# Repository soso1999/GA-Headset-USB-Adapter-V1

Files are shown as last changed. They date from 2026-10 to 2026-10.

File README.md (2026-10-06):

# GA Headset USB Adapter — Dual-GA Aviation Headset to USB for Flight Simulators

DIY-Adapter zum Anschluss eines Dual-GA-Headsets mit zwei Klinkensteckern, beispielsweise eines **Lightspeed Zulu 4**, an einen PC oder Flugsimulator über eine USB-Soundkarte.

> **Nur für PC-/Simulator-Nutzung. Kein zertifiziertes Luftfahrtgerät. Nicht im Flugzeug verwenden und nicht an Flugzeug-Audio-, Funk-, Intercom- oder Bordstromsysteme anschließen.**  
> Siehe [DISCLAIMER](DISCLAIMER.md).

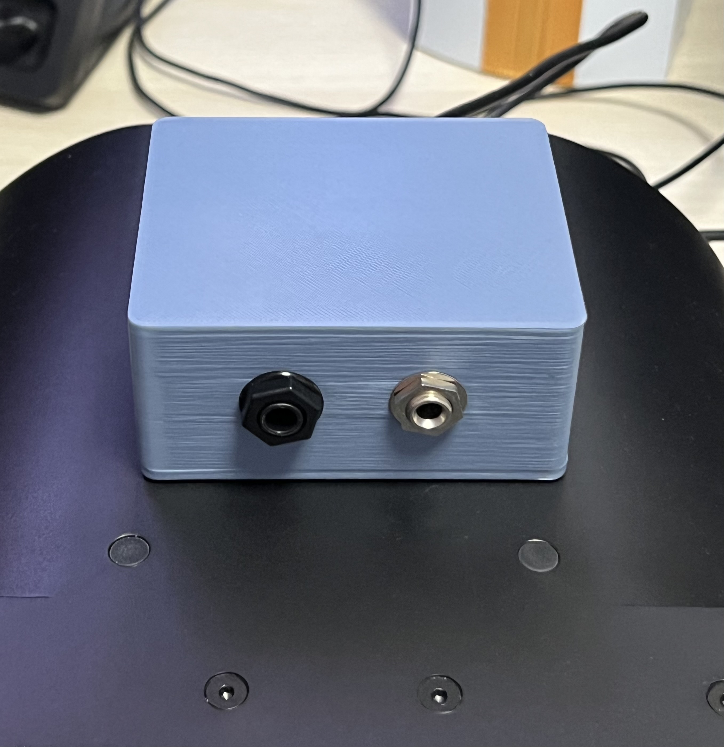
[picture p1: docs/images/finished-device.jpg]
GA Headset USB Adapter V1 für Lightspeed Zulu 4 und Flugsimulator


<a href="https://buymeacoffee.com/soso1999">
  Buy Me a Coffee
</a>

## Stand dieser Veröffentlichung

Der V1-Prototyp wurde gedruckt, aufgebaut und erfolgreich am PC getestet. Mikrofonaufnahme und Wiedergabequalität sind sehr gut.

Der Aufbau wurde erfolgreich mit einem **Lightspeed Zulu 4 Dual-GA** sowie einem **Bose QC35 II mit AVEE-Mikrofonadapter** getestet.

Dies ist die Dokumentation eines funktionierenden Einzelprototyps und keine messtechnische, sicherheitstechnische oder allgemeine Kompatibilitätsfreigabe.

**Dokumentationsstand: v1.0.0**

## Stückliste (BOM)

| Anzahl | Bauteil | Wert / Typ | Hinweise |
|---:|---|---|---|
| 1 | USB-Soundkarte | DollaTek Free Drive USB-Soundkarte | Stellt Mikrofoneingang und Stereo-Kopfhörerausgang bereit |
| 1 | DC-DC-Step-Up-Wandler | GTIWUNG 5 V → 12 V Boost Converter | Wird aus USB 5 V versorgt und erzeugt die Mikrofon-Bias-Spannung |
| 1 | Mikrofonbuchse | PJ-068 Aviation-Mikrofonbuchse | Für den GA-Mikrofonstecker |
| 1 | Kopfhörerbuchse | Neutrik NMJ3HF-S | 6,35 mm / 1/4" Stereo-Klinkenbuchse |
| 1 | Lochrasterplatine | ca. 60 × 40 mm | Abmessungen können je nach Aufbau variieren |
| 1 | Widerstand R1 | 22 Ω | Bestandteil des Versorgungsfilters |
| 1 | Widerstand R2 | 220 Ω | Bias-Widerstand für das Mikrofon |
| 1 | Widerstand R3 | 10 kΩ | Serienwiderstand zum Mikrofoneingang der USB-Soundkarte |
| 1 | Elko C1 | 470 µF / mindestens 25 V | Glättung der Versorgungsspannung; Polarität beachten |
| 1 | Keramikkondensator C2 | 100 nF / mindestens 25 V | HF-Entstörung der Versorgung |
| 1 | Folienkondensator C3 | 1 µF WIMA | Gleichspannungsentkopplung / Audio-Koppelkondensator |
| – | Schaltdraht / Litze | nach Aufbau | Interne Verdrahtung |
| – | Schrumpfschlauch / Isolierung | nach Aufbau | Zur elektrischen Isolation |
| 1 | USB-Anschlusskabel | USB-A-Stecker auf offenes Kabelende | Mindestens 4-adriges USB-2.0-Kabel für +5 V, GND, D+ und D− |
| 1 | 3D-gedrucktes Gehäuse | Eigenkonstruktion | Für 60 × 40 mm Platine und beide Aviation-Buchsen |
| 4 | M3-Schrauben | – | Für den Gehäusedeckel |
| 4 | M3-Gewindeeinsätze | Heat-Set Inserts | Werden mit dem Lötkolben in das Gehäuse eingeschmolzen |

Die ausführliche Stückliste befindet sich unter [hardware/BOM.md](hardware/BOM.md) bzw. [hardware/BOM.csv](hardware/BOM.csv).

Die 12-V-Mikrofon-Bias-Spannung des USB-Adapters versorgt ausschließlich das Elektret-Mikrofon. Sie speist nicht die ANR- oder Bluetooth-Elektronik des Headsets. Beim Lightspeed Zulu 4 Dual-GA erfolgt deren Versorgung weiterhin über die beiden AA-Batterien.

LEMO- und Helikopter-Stecker werden von dieser Version nicht unterstützt.

### Mikrofon-Signalweg

USB 5 V → Step-Up auf 12 V → 22-Ω-Filterwiderstand →  
gefilterter Versorgungspunkt mit 470-µF-Elko und 100-nF-Kondensator gegen GND →  
220-Ω-Mikrofon-Bias-Widerstand →  
Ring der PJ-068-Mikrofonbuchse

Mikrofon-Ring → 1-µF-Koppelkondensator → 10-kΩ-Widerstand →  
MIC-Eingang der USB-Soundkarte

PJ-068 Sleeve → gemeinsame Masse (GND)

PJ-068 Tip → nicht belegt

### Kopfhörerausgang

Der Stereo-Ausgang der USB-Soundkarte wird direkt an die 6,35-mm-Aviation-Kopfhörerbuchse geführt.

- Tip = linker Kanal
- Ring = rechter Kanal
- Sleeve = Masse (GND)

Eine zusätzliche Hardware-Mono-Mischung wird in Version 1 nicht verwendet.

Für eine korrekte Links-/Rechts-Kanaltrennung sollte das Headset auf Stereo gestellt werden. Beim Lightspeed Zulu 4 kann die Wiedergabe auch in der Stellung Mono normal funktionieren; dabei kann jedoch die echte Stereo-Kanaltrennung verloren gehen.

Alle Masseverbindungen der Schaltung verwenden einen gemeinsamen GND.

## Dokumentation und Dateien

| Inhalt | Datei |
|---|---|
| Stückliste | [BOM](hardware/BOM.md), [CSV](hardware/BOM.csv) |
| Elektrischer Schaltplan | [Schaltplan](hardware/schematic.md) |
| Anschluss für Anschluss | [Verdrahtung](docs/wiring.md) |
| Aufbau und Inbetriebnahme | [Bauanleitung](docs/build.md) |
| Störungen und bekannte Grenzen | [Troubleshooting](docs/troubleshooting.md) |
| Gehäuse und 3D-Druck | [CAD](cad/README.md) |
| Quellen und Projektstand | [Provenienz](docs/provenance.md) |
| Release Notes | [v1.0.0](releases/v1.0.0.md) |

## Prinzip

```text
                              ┌──────── Kopfhörer L ───── J2 Tip
PC ─ USB ─ USB-Soundkarte ────┼──────── Kopfhörer R ───── J2 Ring
       │                      └──────── Kopfhörer GND ─── J2 Sleeve
       │
       │                     MIC-IN
       │                        ↑
       │                      10 kΩ
       │                        ↑
       │                       C3
       │                        ↑
       │                 GA-Mikrofon-Ring
       │                        ↑
       │                      220 Ω
       │                        ↑
       └─ +5 V ─ Step-Up 12 V ─ Filter

Alle vorgesehenen Masseanschlüsse teilen einen gemeinsamen GND.
```

Der Kopfhörerausgang bleibt **Stereo**. Es findet keine passive Mono-Zusammenführung statt.

## Direct Monitoring / Sidetone

V1 enthält kein analoges Direct Monitoring bzw. Sidetone.

Software-Monitoring über Windows oder entsprechende Audio-Software ist möglich, kann jedoch eine deutlich hörbare Verzögerung verursachen.

Eine analoge Sidetone-/Preamp-Lösung ist als mögliche spätere V2 vorgesehen und nicht Bestandteil von V1.

## Unterstützung

Wenn dir das Projekt beim Einsatz deines Aviation-Headsets im Simulator hilft, kannst du die weitere Entwicklung freiwillig mit einem Kaffee unterstützen. Die Dateien bleiben frei verfügbar.

<a href="https://buymeacoffee.com/soso1999">
  Buy Me a Coffee
</a>

## Lizenz

Für die verschiedenen Bestandteile des Projekts gelten unterschiedliche Lizenzen:

- Hardware-Design, elektrische Schaltungs-/Verdrahtungsdokumentation und CAD-Dateien: **CERN Open Hardware Licence Version 2 – Permissive (`CERN-OHL-P-2.0`)**
- Allgemeine Dokumentation, README, Release Notes und Gerätefotos: **Creative Commons Attribution 4.0 International (`CC-BY-4.0`)**

Die vollständigen Lizenztexte und die genaue Zuordnung befinden sich unter [LICENSES](LICENSES/README.md).

Copyright © 2026 Josef Jankarashvili.

Lightspeed, Zulu, Bose und weitere genannte Hersteller- oder Produktnamen sind Marken ihrer jeweiligen Rechteinhaber. Dieses Projekt ist unabhängig und wird von den genannten Herstellern weder unterstützt noch zertifiziert.

Die elektrischen Herstellerdaten des Lightspeed Zulu 4 wurden anhand der [offiziellen Zulu-4-Spezifikation](https://www.lightspeedaviation.com/product/zulu-4-anr-headset/) geprüft. Weitere Quellen befinden sich in der Provenienz-Dokumentation.

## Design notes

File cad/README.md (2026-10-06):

# Gehäuse

| Teil | Datei |
|---|---|
| Unterteil | [ga_headset_interface_base.stl](stl/ga_headset_interface_base.stl) |
| Deckel | [ga_headset_interface_lid.stl](stl/ga_headset_interface_lid.stl) |
| Parametrische OpenSCAD-Quelldatei | [ga_headset_interface_case.scad](ga_headset_interface_case.scad) |

## Abmessungen

- Außenmaß des Gehäuses: 92 × 76 × 40 mm
- Wandstärke: 2,6 mm
- vorgesehene Platine: 60 × 40 mm
- Bohrung für GA-Mikrofonbuchse: ca. 9,7 mm
- Bohrung für 6,35-mm-Kopfhörerbuchse: ca. 11,5 mm
- USB-Kabelschlitz: 8 mm
- Aufnahmen für M3-Heat-Set-Inserts: ca. 4,2 mm
- vorgesehene Insert-Länge: ca. 5 mm

Die veröffentlichten STL-Dateien wurden für den V1-Prototyp gedruckt und erfolgreich mit der 60 × 40-mm-Platine sowie den verwendeten Buchsen montiert.

## Druckempfehlung

Als Material eignen sich PLA oder PETG.

Empfohlene Ausgangswerte:

- Schichthöhe: 0,2 mm
- mindestens drei Außenwände
- STL-Einheiten: Millimeter

Das Unterteil sollte mit dem Gehäuseboden auf dem Druckbett liegen. Der Deckel wird mit seiner flachen Außenseite auf dem Druckbett gedruckt.

Überhänge an den Buchsenöffnungen und inneren Auflagen sollten im Slicer kontrolliert werden. Falls erforderlich, können dort Stützstrukturen aktiviert werden.

Aufgrund von Drucker-, Material- und Slicer-Toleranzen empfiehlt es sich, insbesondere die Passung der Buchsen und Heat-Set-Inserts vor der endgültigen Montage zu kontrollieren.

## Montage

Die M3-Heat-Set-Inserts vorsichtig mit einem Lötkolben einschmelzen und rechtwinklig ausrichten.

Die Schraubenlänge entsprechend Deckeldicke, Insert-Tiefe und tatsächlich verfügbarem Gewinde wählen.

Die Platine elektrisch isoliert im Gehäuse befestigen. Das USB-Kabel sollte zusätzlich mechanisch zugentlastet werden.

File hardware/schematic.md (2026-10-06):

# Elektrischer Schaltplan — V1

Dieser Schaltplan dokumentiert den tatsächlich aufgebauten und getesteten Signalweg des GA-Headset-USB-Adapters V1. Die angegebenen Bauteilwerte entsprechen der funktionierenden V1-Hardware. Der Schaltplan stellt die elektrische Funktion dar und nicht zwingend die physische Anordnung der Bauteile auf der Lochrasterplatine.

```text
USB-A
├── +5 V ────────────────┬──────── U1 USB +5 V
│                        └──────── U2 IN+
│
├── D− ─────────────────────────── U1 USB D−
├── D+ ─────────────────────────── U1 USB D+
│
└── GND ────────────────┬──────── U1 USB GND
                        └──────── U2 IN−

U2 OUT− ────────────────────────── gemeinsame Masse
          (bei nicht isoliertem Step-Up mit IN− verbunden)

MIKROFONVERSORGUNG UND -SIGNAL

U2 OUT+ (12 V) ─ R1 22 Ω ─── ─┬── R2 220 Ω ────● MIC_BIAS_AUDIO
                              │                  │
                         ┌────┴────┐             ├── J1 Ring
                         │         │             │
                     C1 470 µF  C2 100 nF        └── C3 1 µF ─ R3 10 kΩ ─ U1 MIC signal
                     (+ oben)      │
                         │         │
GND ─────────────────────┴─────────┴──────────── J1 Sleeve / U1 MIC ground

J1 Tip: unbeschaltet
        (kein elektrisches PTT in diesem Adapter)

KOPFHÖRERAUSGANG

U1 Headphone L ─────────────────── J2 Tip
U1 Headphone R ─────────────────── J2 Ring
U1 Headphone GND ───────────────── J2 Sleeve ─ GND

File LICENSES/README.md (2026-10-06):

# Lizenzzuordnung

Copyright © 2026 Josef Jankarashvili.

Für die verschiedenen Bestandteile dieses Projekts gelten folgende Lizenzen:

- `cad/**`, `hardware/**` sowie die elektrische Schaltungs-, Verdrahtungs- und Aufbaudokumentation:
  **CERN Open Hardware Licence Version 2 – Permissive (`CERN-OHL-P-2.0`)**.  
  Der vollständige Lizenztext befindet sich unter `LICENSES/CERN-OHL-P-2.0.txt`.

- Allgemeine Dokumentation, `README.md`, Release Notes, Fotos und sonstige nicht zur Hardwarekonstruktion gehörende Inhalte:
  **Creative Commons Attribution 4.0 International (`CC-BY-4.0`)**.  
  Der vollständige Lizenztext befindet sich unter `LICENSES/CC-BY-4.0.txt`.

Die Lizenztexte selbst bleiben unverändert und werden unter den Bedingungen ihrer jeweiligen Urheber bereitgestellt.

Bei Weitergabe oder Bearbeitung müssen die jeweils geltenden Lizenz- und Attributionshinweise erhalten bleiben.

Hersteller- und Produktnamen sowie Marken werden ausschließlich zur Beschreibung kompatibler oder verwendeter Produkte genannt. Ihre Verwendung bedeutet weder eine Zugehörigkeit zu noch eine Unterstützung oder Zertifizierung durch die jeweiligen Rechteinhaber.

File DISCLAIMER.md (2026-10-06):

# Nutzungshinweis / Disclaimer

**Nur für PC und Flugsimulator. Kein zertifiziertes Luftfahrtgerät. Nicht für den Einsatz im Flugzeug.**

Dieser Selbstbauadapter ist ausschließlich für die Verwendung an einem PC bzw. Flugsimulator vorgesehen. Er darf nicht an Flugzeug-Bordnetze, Flugzeug-Funkgeräte, Intercom-Systeme oder andere flugbetriebliche bzw. sicherheitskritische Systeme angeschlossen werden. Er ersetzt, ergänzt oder verändert keine zertifizierte Flugzeugausrüstung.

Aufbau und Nutzung erfolgen auf eigene Verantwortung. Fehlerhafte Verdrahtung, Verpolung, Kurzschlüsse oder falsche Spannungen können USB-Port, Soundkarte, Headset oder andere Bauteile beschädigen.

Vor dem Anschluss eines Headsets müssen insbesondere Pinbelegung, Masseverbindungen, Versorgungsspannungen und die Trennung von Gleich- und Audiosignal überprüft werden.

Der verwendete Koppelkondensator dient ausschließlich zur Gleichspannungsentkopplung des Audiosignals. Er stellt keine galvanische Isolation und keine vollständige Schutz- oder Fehlerabsicherung dar.

Der erfolgreiche Betrieb eines einzelnen Prototyps stellt keine elektrische, EMV-technische, sicherheitstechnische oder behördliche Prüfung bzw. Zertifizierung dar.

Es wird keine allgemeine Kompatibilität mit anderen Headsets, USB-Soundkarten, Computern oder Betriebsbedingungen zugesichert.

Die im Repository enthaltenen Dateien und Dokumentationen werden unter den jeweils angegebenen Lizenzen bereitgestellt. Die dort enthaltenen Gewährleistungs- und Haftungsausschlüsse gelten im Rahmen der jeweiligen Lizenz und soweit gesetzlich zulässig. Zwingende gesetzliche Haftungsvorschriften bleiben unberührt.

**For simulator/PC use only. This is not certified aviation equipment. Do not use it in an aircraft or connect it to aircraft audio, radio, intercom or power systems. Build and use at your own risk.**

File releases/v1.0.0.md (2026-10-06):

# v1.0.0 — GA Headset USB Adapter

Der V1-Prototyp wurde erfolgreich aufgebaut und im PC-/Simulatorbetrieb getestet.

## Enthalten

- USB-Soundkarten-Anbindung für Dual-GA-Headsets.
- Erfolgreich getestet mit dem Lightspeed Zulu 4 sowie einem Bose QC35 II mit AVEE-Mikrofonadapter.
- 5-V-USB-Versorgung mit Step-Up auf 12 V für die Mikrofon-Bias-Spannung.
- Versorgungsfilter mit 22 Ω, 470 µF und 100 nF.
- Mikrofon-Bias über 220 Ω.
- AC-gekoppelter Mikrofonpfad über 1-µF-Koppelkondensator und 10-kΩ-Serienwiderstand zum MIC-Eingang der USB-Soundkarte.
- Direkter Stereo-Kopfhörerausgang:
  - Tip = linker Kanal
  - Ring = rechter Kanal
  - Sleeve = GND
- Keine Hardware-Mono-Zusammenführung und kein zusätzlicher Kopfhörerverstärker.
- 3D-gedrucktes Gehäuse mit Unterteil und verschraubtem Deckel.
- STL-Dateien sowie parametrische OpenSCAD-Quelldatei des Gehäuses.
- Foto des aufgebauten und getesteten V1-Prototyps.
- Stückliste als Markdown und CSV.
- Elektrischer Schaltplan, Verdrahtungsdokumentation sowie Aufbau- und Inbetriebnahmeanleitung.
- Lizenztexte und Disclaimer.

## Grenzen

- Kein analoges Direct Monitoring bzw. Sidetone.
- Kein zusätzlicher Mikrofon-Preamp oder Kopfhörerverstärker.
- Keine standardisierten EMV-, Rausch-, Frequenzgang- oder Dauerlaufmessungen.
- Ausschließlich für PC- und Simulatorbetrieb vorgesehen.
- Nicht als zertifiziertes Luftfahrtgerät ausgelegt und nicht zur Verwendung im Flugzeug vorgesehen.

Beim getesteten Prototyp konnten anfänglich auftretende elektromagnetische Störgeräusche durch einen größeren Abstand zwischen Adapter und Computer vollständig beseitigt werden.

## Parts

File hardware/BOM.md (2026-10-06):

# Stückliste – GA Headset USB Adapter V1

Diese Stückliste beschreibt die in Version 1 verwendeten Bauteile des GA-Headset-USB-Adapters.

| Referenz | Menge | Bauteil | Wert / Typ | Status / Hinweis |
|---|---:|---|---|---|
| U1 | 1 | USB-Soundkarte | MIC-IN + Stereo-Kopfhörerausgang | DollaTek Free Drive USB-Soundkarte; Pinbelegung und Eingangsbias prüfen |
| U2 | 1 | Step-Up | 5 V auf 12 V | GTIWUNG Mini Boost Modul 3,7 V bis 12 V; Ausgang vor Anschluss auf 12 V einstellen |
| R1 | 1 | Widerstand | 22 Ω | Bestandteil des Versorgungsfilters |
| R2 | 1 | Bias-Widerstand | 220 Ω | Mikrofon-Bias |
| R3 | 1 | Signal-Serienwiderstand | 10 kΩ | Zum Mikrofoneingang der USB-Soundkarte |
| C1 | 1 | Filter-Elko | 470 µF / mindestens 25 V | Versorgungsfilter; Polarität beachten |
| C2 | 1 | Filter-Keramikkondensator | 100 nF / mindestens 25 V | HF-Entstörung der Versorgung |
| C3 | 1 | Koppelkondensator | 1 µF WIMA-Folienkondensator | Gleichspannungsentkopplung des Mikrofonsignals |
| J1 | 1 | GA-Mikrofonbuchse | PJ-068 | Ring = Mikrofon-Bias + Signal; Sleeve = GND; Tip unbenutzt |
| J2 | 1 | Kopfhörerbuchse | Neutrik NMJ3HF-S / 6,35 mm | Tip = linker Audiokanal; Ring = rechter Audiokanal; Sleeve = GND |
| PCB | 1 | Lochrasterplatine | 60 × 40 mm | Die Platinenabmessungen können je nach Aufbau variieren |
| CASE | 1 | Gehäuse + Deckel | Original-STLs | 3D-gedrucktes Gehäuse |
| M3 | 4 | Heat-Set-Inserts + Schrauben | M3 | Entwurf ca. 4,2-mm-Bohrung / ca. 5-mm-Insert |
| MISC | 1 | Litze, Isolierung, Schrumpfschlauch, Zugentlastung | nach Aufbau | Für interne Verdrahtung und mechanische Sicherung |
| CBL1 | 1 | USB-Anschlusskabel | USB-A-Stecker auf offenes Kabelende | Für Datenverbindung und 5-V-Versorgung; mindestens 4-adriges USB-2.0-Kabel; Adern vor Anschluss durchmessen und nicht allein nach Farbe zuordnen |

## Mikrofon-Signalweg

USB 5 V → Step-Up auf 12 V → 22-Ω-Filterwiderstand → 470-µF-Elko + 100-nF-Kondensator → 220-Ω-Bias-Widerstand → Ring der PJ-068-Mikrofonbuchse.

Das Mikrofonsignal wird am Ring abgegriffen und über den 1-µF-Koppelkondensator sowie den 10-kΩ-Serienwiderstand zum Mikrofoneingang der USB-Soundkarte geführt.

- PJ-068 Ring: Mikrofon-Bias + Audiosignal
- PJ-068 Sleeve: Masse (GND)
- PJ-068 Tip: nicht verwendet

## Kopfhörerausgang

Der Kopfhörerausgang wird **stereo** betrieben.

- Tip: linker Audiokanal
- Ring: rechter Audiokanal
- Sleeve: Masse (GND)

Eine zusätzliche Hardware-Mono-Mischung mit Widerständen wird in Version 1 nicht verwendet.

## Hinweise

Vor dem Anschluss des Headsets muss der Step-Up-Wandler auf etwa 12 V Ausgangsspannung eingestellt und mit einem Multimeter kontrolliert werden.

Alle Masseverbindungen der Schaltung verwenden einen gemeinsamen GND.

Der Adapter ist ausschließlich für PC- und Simulatorbetrieb vorgesehen und nicht als zertifiziertes Luftfahrtgerät ausgelegt.

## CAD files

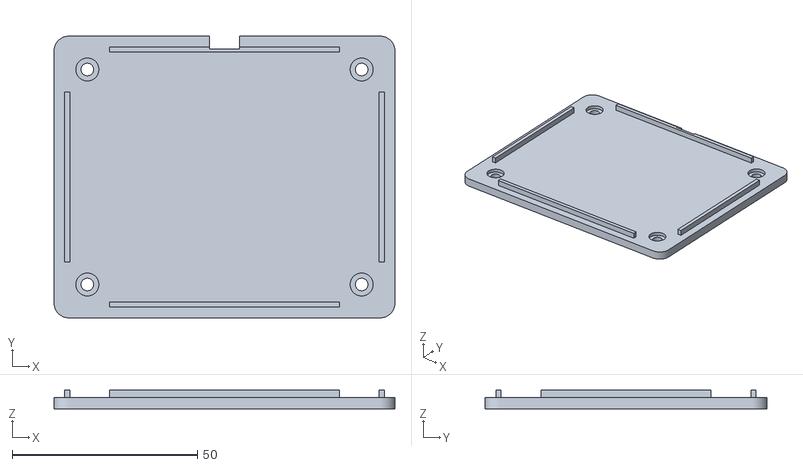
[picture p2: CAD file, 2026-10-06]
cad/stl/ga_headset_interface_lid.stl
92.0 x 76.0 x 5.00

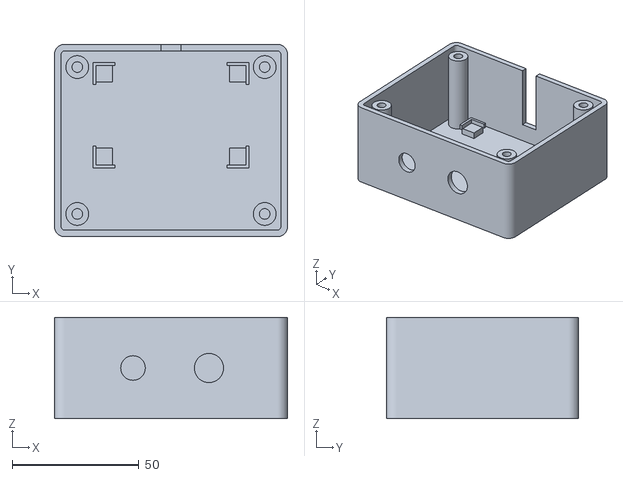
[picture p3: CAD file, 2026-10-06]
cad/stl/ga_headset_interface_base.stl
92.0 x 76.0 x 40.0

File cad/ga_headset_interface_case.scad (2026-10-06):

// SPDX-License-Identifier: CERN-OHL-P-2.0
// Copyright 2026 Josef Jankarashvili / GA Headset USB Adapter contributors
// Original STL meshes recovered from the project conversation.
// This is an STL-import wrapper, NOT the missing original parametric source.
// Dimensions, holes and insert sockets cannot be parametrically edited here.
part = "base"; // [base,lid,both]
module base() { import("stl/ga_headset_interface_base.stl", convexity=10); }
module lid() { import("stl/ga_headset_interface_lid.stl", convexity=10); }
if (part == "base") base();
else if (part == "lid") lid();
else if (part == "both") { base(); translate([115,0,0]) lid(); }
else assert(false, "part must be base, lid or both");

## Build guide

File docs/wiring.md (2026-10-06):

# Verdrahtung

Vor dem Löten stromlos prüfen, welcher Lötanschluss tatsächlich Tip, Ring bzw. Sleeve entspricht. Buchsen können zusätzliche Schaltkontakte besitzen; deren Lage ist nicht universell. Einen passenden Stecker einstecken und jeden Kontakt mit dem Multimeter bis zum jeweiligen Lötanschluss durchmessen.

| Von | Nach |
|---|---|
| USB +5 V | Step-Up IN+ |
| USB GND | gemeinsame Masse |
| Step-Up IN− | gemeinsame Masse |
| Step-Up OUT− | gemeinsame Masse |
| Step-Up OUT+ | R1 = 22 Ω |
| anderes Ende R1 | gefilterter 12-V-Versorgungspunkt |
| gefilterter 12-V-Versorgungspunkt | C1 Plus |
| C1 Minus | gemeinsame Masse |
| gefilterter 12-V-Versorgungspunkt | ein Anschluss von C2 = 100 nF |
| anderer Anschluss von C2 | gemeinsame Masse |
| gefilterter 12-V-Versorgungspunkt | R2 = 220 Ω |
| anderes Ende R2 | J1 Ring |
| J1 Ring | Eingang C3 = 1 µF |
| Ausgang C3 | R3 = 10 kΩ |
| anderes Ende R3 | identifizierter MIC-Signalanschluss der USB-Soundkarte |
| J1 Sleeve | gemeinsame Masse |
| Soundkarte MIC-GND | gemeinsame Masse |
| Soundkarte Kopfhörer L | J2 Tip |
| Soundkarte Kopfhörer R | J2 Ring |
| Soundkarte Kopfhörer-GND | J2 Sleeve / gemeinsame Masse |

## Buchsenbelegung

### J1 – GA-Mikrofonbuchse PJ-068

- Ring = Mikrofon-Bias + Mikrofonsignal
- Sleeve = GND
- Tip = unbeschaltet

### J2 – 6,35-mm-Kopfhörerbuchse

- Tip = linker Audiokanal
- Ring = rechter Audiokanal
- Sleeve = GND

Der Kopfhörerausgang wird in V1 direkt stereo verdrahtet. Eine passive Mono-Zusammenführung oder zusätzliche Mischwiderstände R4/R5 werden nicht verwendet.

Bei einem Headset mit abweichender Anschlussbelegung müssen vor dem Anschluss die Herstellerunterlagen geprüft werden.

Die Belegung des MIC-Eingangs verschiedener USB-Soundkarten ist nicht einheitlich. Deshalb legt diese Anleitung absichtlich keinen allgemein gültigen Tip-/Ring-Kontakt für einen 3,5-mm-Mikrofoneingang fest. Die tatsächliche Belegung der verwendeten Soundkarte muss vor dem Anschluss identifiziert werden.

## Hinweise zur Leitungsführung

Mikrofonsignal und zugehörige Masse möglichst dicht nebeneinander bzw. verdrillt führen.

Den Step-Up-Wandler und seine stromführenden Leitungen möglichst weit von der empfindlichen Mikrofon-Signalleitung entfernt anordnen.

Masseverbindungen kurz und zuverlässig ausführen.

Das USB-Kabel mechanisch zugentlasten. Der Kabelschlitz im Gehäuse allein stellt keine ausreichende Zugentlastung dar.

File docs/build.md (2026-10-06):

# Aufbau und Inbetriebnahme

1. USB-Anschlusskabel vorbereiten. Verwendet wird ein USB-A-Kabel mit mindestens vier Adern für +5 V, GND, D+ und D−. Die Adern vor dem Anschluss durchmessen und nicht allein anhand ihrer Farbe zuordnen.

2. USB-Soundkarte einzeln am PC testen. MIC-Signal, MIC-Masse sowie Kopfhörer links, rechts und GND identifizieren.

3. Step-Up-Wandler zunächst ohne angeschlossenes Headset betreiben. Eingang mit USB-5-V versorgen und die Ausgangsspannung zwischen OUT+ und OUT− mit einem Multimeter auf etwa 12 V einstellen.

4. Versorgungsfilter aufbauen:

   - 12-V-Ausgang des Step-Up-Wandlers → R1 = 22 Ω
   - hinter R1 entsteht der gefilterte 12-V-Versorgungspunkt
   - C1 = 470 µF zwischen diesem Versorgungspunkt und GND
   - C2 = 100 nF parallel zu C1 zwischen Versorgungspunkt und GND

   Beim Elektrolytkondensator C1 muss der Pluspol zur gefilterten Versorgung und der Minuspol zu GND zeigen. C2 ist unpolarisiert.

5. Mikrofonzweig aufbauen:

   - gefilterte 12 V über R2 = 220 Ω zum Ring der PJ-068-Mikrofonbuchse
   - Sleeve der PJ-068-Buchse an gemeinsamen GND
   - Tip der PJ-068-Buchse bleibt in diesem Adapter unbenutzt

6. Das Mikrofonsignal am Ring der PJ-068-Buchse abgreifen und über C3 = 1 µF sowie R3 = 10 kΩ zum MIC-Eingang der USB-Soundkarte führen.

   C3 dient zur Gleichspannungsentkopplung. Dadurch gelangt die externe 12-V-Mikrofon-Bias-Spannung nicht als Gleichspannung zum MIC-Eingang der USB-Soundkarte.

7. Kopfhörerausgang stereo verdrahten:

   - linker Ausgang der USB-Soundkarte → Tip der 6,35-mm-Kopfhörerbuchse
   - rechter Ausgang der USB-Soundkarte → Ring der 6,35-mm-Kopfhörerbuchse
   - GND der USB-Soundkarte → Sleeve der Kopfhörerbuchse

   In V1 wird keine zusätzliche Hardware-Mono-Mischung verwendet.

8. Alle Masseverbindungen gemeinsam verbinden:

   - USB-GND
   - Step-Up OUT−
   - Mikrofon-Sleeve
   - MIC-GND der USB-Soundkarte
   - Kopfhörer-Sleeve

9. Vor dem ersten Einschalten bei stromloser Schaltung auf Kurzschlüsse prüfen. Insbesondere darf keine niederohmige Verbindung zwischen +12 V und GND, MIC-IN oder den Kopfhörerausgängen bestehen.

10. Versorgung zunächst ohne angeschlossenes Headset einschalten und nochmals kontrollieren:

    - Step-Up-Ausgang etwa 12 V
    - gefilterte Versorgung vorhanden
    - die externe 12-V-Bias-Spannung darf hinter C3 nicht am MIC-Eingang der USB-Soundkarte anliegen

    Eine geringe, von der USB-Soundkarte selbst erzeugte Mikrofon-Bias-Spannung am MIC-Eingang kann konstruktionsbedingt vorhanden sein und ist nicht mit der externen 12-V-Versorgung zu verwechseln.

11. Vor dem Einstecken des Headsets die USB-Versorgung des Adapters trennen. Headset anschließen und die Kopfhörerlautstärke zunächst niedrig einstellen.

    Der Adapter stellt einen echten Stereo-Ausgang bereit. Für korrekte Links-/Rechts-Kanaltrennung sollte das Headset auf Stereo gestellt werden. Das Lightspeed Zulu 4 kann auch in der Stellung Mono normal funktionieren; dabei kann jedoch die echte Stereo-Kanaltrennung verloren gehen.

12. USB-Versorgung wieder anschließen und Funktion testen:

    - Mikrofonaufnahme prüfen
    - Mikrofonpegel in Windows so einstellen, dass Sprache ausreichend laut und ohne Clipping aufgenommen wird
    - bei auf Stereo gestelltem Headset linken und rechten PC-Kanal getrennt testen:
      - linker Kanal → linke Ohrmuschel
      - rechter Kanal → rechte Ohrmuschel

13. Beim getesteten Lightspeed Zulu 4 Dual-GA wird die ANR-/Headset-Elektronik weiterhin über die beiden AA-Batterien des Headsets versorgt. Die 12-V-Versorgung dieses Adapters dient ausschließlich dem Mikrofonzweig und versorgt nicht die ANR- oder Bluetooth-Elektronik.

14. Vor dem endgültigen Einbau auf mögliche elektromagnetische Störungen achten. Beim V1-Prototyp traten in unmittelbarer Nähe des Computers Störgeräusche im Mikrofonsignal auf. Durch einen größeren Abstand zwischen Adapter und Computer verschwanden diese vollständig.

15. Nach erfolgreichem Test die Platine elektrisch isoliert im Gehäuse befestigen, das USB-Kabel mechanisch zugentlasten und den Gehäusedeckel montieren.

## Direct Monitoring / Sidetone

V1 enthält kein analoges Direct Monitoring bzw. Sidetone.

Software-Monitoring über Windows oder entsprechende Audio-Software ist möglich, kann jedoch aufgrund der zusätzlichen digitalen Signalverarbeitung eine deutlich hörbare Verzögerung verursachen.

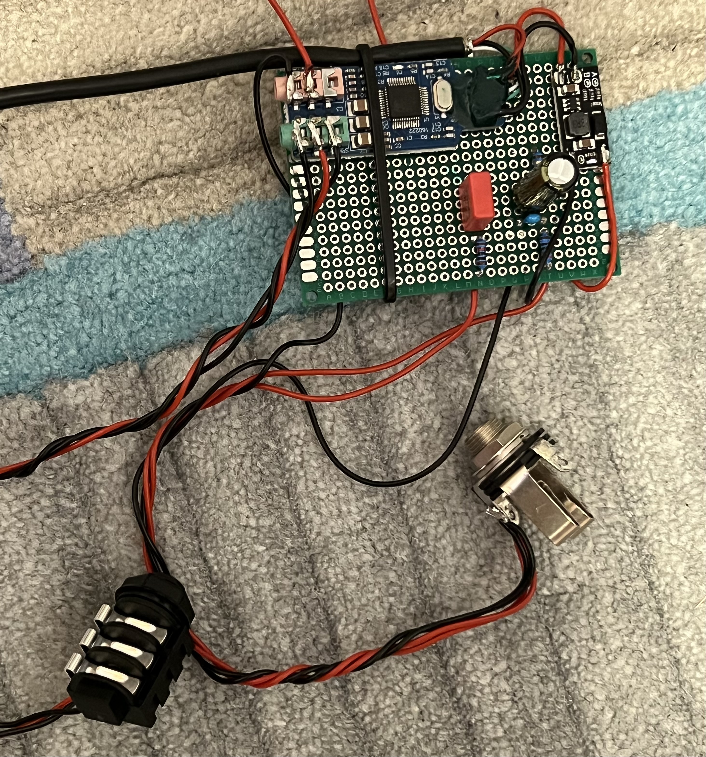
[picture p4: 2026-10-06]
docs/images/ga-headset-usb-adapter-v1-internal-wiring.jpg

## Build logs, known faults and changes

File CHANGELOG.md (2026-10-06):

# Änderungsverlauf

## v1.0.0 — 2026-10-06

Erste veröffentlichte Version des funktionierenden V1-Prototyps.

Enthalten sind die Original-STLs und das Gerätefoto sowie der dokumentierte elektrische Schaltplan, die Stückliste, die Verdrahtung, die Aufbau- und Inbetriebnahmeanleitung, der Disclaimer und die Lizenzzuordnung.

## Spätere Entwicklung

Analoger Sidetone und ein zusätzlicher Mikrofon-Preamp sind separat als V2 geplant und kein Bestandteil von V1.

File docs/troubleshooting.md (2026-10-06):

# Bekannte Grenzen und Störungen

- **Piepen bzw. Störgeräusch in der Mikrofonaufnahme:** Beim V1-Prototyp trat in unmittelbarer Nähe des Computers ein leises periodisches Störgeräusch auf. Ein größerer Abstand zwischen Adapter und Computer beseitigte die Störung vollständig. Dies spricht für elektromagnetische Einkopplung aus der Umgebung. Die konkrete Störquelle wurde nicht messtechnisch bestimmt. Mögliche Quellen sind insbesondere Computer, Netzteil, GPU-/Mainboard-Spannungswandler, Monitor oder andere Schaltnetzteile. Kurze Mikrofonleitungen, gemeinsam geführte bzw. verdrillte Signal-/GND-Leitungen und ausreichender Abstand zu starken Störquellen können helfen.

- **Step-Up-Wandler:** Ein Schaltwandler kann grundsätzlich Störungen erzeugen, insbesondere bei geringer Last oder im Burst-Betrieb. Im V1-Prototyp wurde testweise ein 1-kΩ-Lastwiderstand parallel zum 12-V-Ausgang angeschlossen; dies führte zu keiner Verbesserung des beobachteten Störgeräuschs. Der 1-kΩ-Widerstand gehört daher nicht zur V1-Stückliste.

- **Kein oder zu leises Mikrofon:** Pinbelegung der PJ-068-Buchse, gemeinsamen Ground, Mikrofon-Bias-Spannung und Verbindung zum MIC-Eingang der USB-Soundkarte prüfen. Der Adapter ist für einen Mikrofoneingang ausgelegt; ein Line-Eingang benötigt einen deutlich höheren Signalpegel und ist dafür nicht vorgesehen.

- **Nur ein Ohr bzw. fehlender Stereokanal:** Verdrahtung der 6,35-mm-Kopfhörerbuchse kontrollieren:
  - Tip = linker Kanal
  - Ring = rechter Kanal
  - Sleeve = GND

  Für echte Links-/Rechts-Kanaltrennung sollte das Headset auf Stereo gestellt werden. Beim Lightspeed Zulu 4 kann die Wiedergabe auch in der Stellung Mono funktionieren; dabei kann jedoch die Stereo-Kanaltrennung verloren gehen.

- **Zu wenig Kopfhörerpegel:** V1 verwendet den Stereo-Kopfhörerausgang der USB-Soundkarte direkt und besitzt keinen zusätzlichen Kopfhörerverstärker. Der erreichbare Pegel hängt daher von der verwendeten USB-Soundkarte und der Impedanz bzw. Empfindlichkeit des angeschlossenen Headsets ab.

- **Eigene Stimme verzögert:** V1 besitzt kein analoges Direct Monitoring bzw. Sidetone. Bei Software-Monitoring über Windows oder Audio-Software durchläuft das Mikrofonsignal zusätzliche A/D-, Software- und D/A-Stufen, wodurch eine hörbare Verzögerung entstehen kann. Ein analoges, praktisch latenzfreies Sidetone ist für eine spätere Version vorgesehen.

- **Gehäuse und elektromagnetische Abschirmung:** PLA und PETG bieten praktisch keine zuverlässige elektromagnetische Abschirmung. Beim getesteten V1-Prototyp war eine zusätzliche Abschirmung jedoch nicht erforderlich, nachdem der Adapter mit ausreichendem Abstand zum Computer betrieben wurde. Eine nachträgliche Auskleidung mit leitfähiger Folie ist grundsätzlich möglich, muss jedoch elektrisch sicher isoliert werden, damit keine Leiterbahnen oder Lötstellen kurzgeschlossen werden.

## Einschränkungen der Erprobung

Der V1-Prototyp wurde im praktischen PC-/Simulatorbetrieb erfolgreich mit einem Lightspeed Zulu 4 Dual-GA getestet.

Es wurden jedoch keine standardisierten Messungen zu Rauschpegel, Frequenzgang, Klirrfaktor, elektromagnetischer Verträglichkeit oder Langzeitbetrieb durchgeführt.

Aus dem erfolgreichen Betrieb des getesteten Aufbaus kann daher keine allgemeine Kompatibilität oder Freigabe für andere GA-Headsets, USB-Soundkarten oder Hardwarekonfigurationen abgeleitet werden.

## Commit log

2026-10-06 Update BOM.csv with new component details
    [BOM.csv]
2026-10-06 Add USB connection cable to BOM
    [BOM.csv]
2026-10-06 Add USB connection cable details to BOM
    Added details for USB connection cable in BOM.
2026-10-06 Revise schematic with USB connections and details
    Updated the schematic to include USB connections and component values.
2026-10-06 Add internal wiring image for USB adapter v1
2026-10-06 Fix formatting in schematic.md
2026-10-06 Update BOM.md to remove hardware check note for M3
    Removed note about checking actual hardware for M3 inserts.
2026-10-06 Update BOM.csv with new entries
    [BOM.csv]
2026-10-06 Enhance README with dimensions and printing guidelines
    Updated the README with detailed dimensions and printing recommendations for the headset case.
2026-10-06 Revise wiring documentation and pinout details
    Updated wiring instructions and clarified connections for components. Added details about microphone and headphone jack pinouts.
2026-10-06 Revise component details in BOM.csv
    Updated BOM.csv to correct component descriptions and notes.
    [BOM.csv]
2026-10-06 Fix formatting in schematic diagram
